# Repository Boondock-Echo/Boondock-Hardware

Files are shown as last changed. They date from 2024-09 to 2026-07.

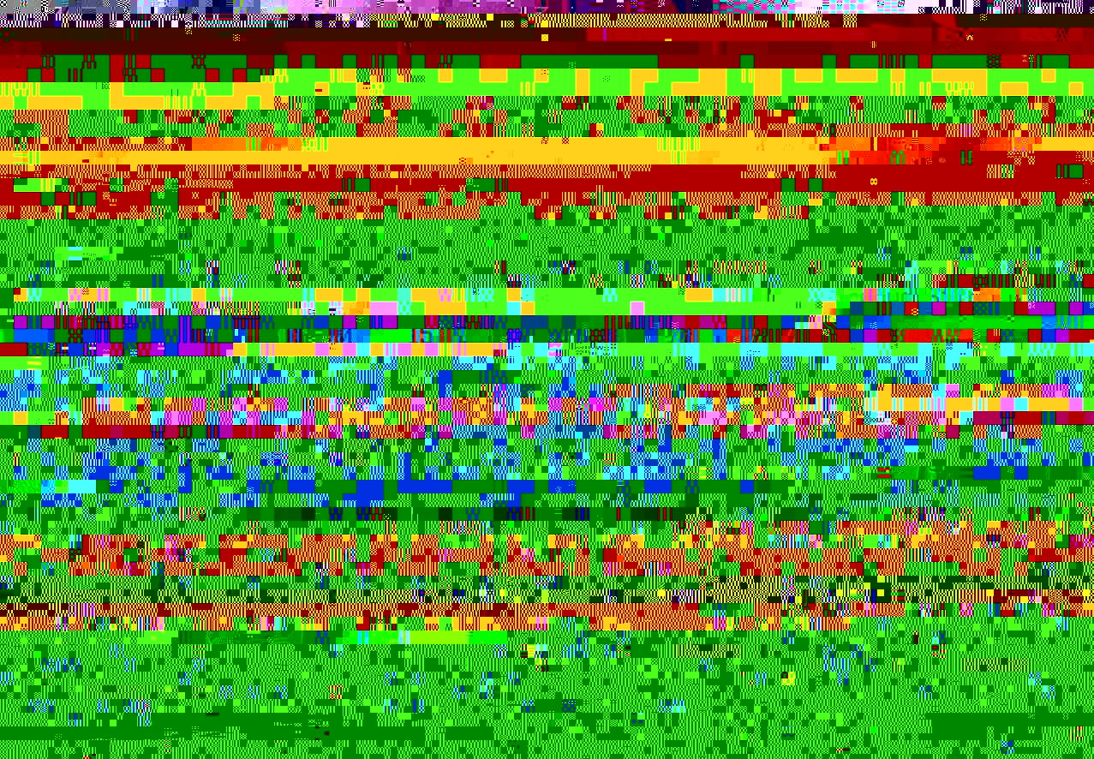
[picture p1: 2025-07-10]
Boondock-Hotel/Media-Assets/Images/BoondockHotel.jpg

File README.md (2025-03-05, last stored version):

# Boondock-Echo 
Hardware Design Files, BOM, Assembly Instructions, etc.

# 3D Files
Complete set of 3D .stl files for printing

# Case
This is the shipping box

# ESP32 Audiokit

# PCB
The KiCad design files for the board

# Software
The firmware for this project is in a different repository.  The easiest way to get started is to create an account at boondockecho.com and do a "firmware upgrade" process there.  Accounts are free.

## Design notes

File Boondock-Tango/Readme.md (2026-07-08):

## 3D Model: BoondockTango_CompleteAssembly v4

# Boondock Tango

**Boondock Tango** is here! We've decided to release a version you can buy and build at home—anywhere in the world. We firmly believe in the power of open-source goodness.

---

## About Boondock Tango

Boondock Tango is a **receive-only device for scanners and radios**

> **Note:** 
> - Currently works on Windows.
> - Mostly works on some flavors of Linux -- We're resolving some issues
> - macOS support is coming soon.

---

## Support Our Work

Designing innovative products takes time. 
If you’re inclined, please consider [buying us a cup of coffee or a can of Diet Dr. Pepper](https://www.paypal.com/ncp/payment/ZGAUS5ZF8CGH6).

---

## Parts & Components

You can find everything you need on eBay, AliExpress, or Amazon. Below is the list we used for the prototypes (we earn 2.5% from these Amazon links):

### Individual Parts
- [Micro USB Cord](https://amzn.to/41zijAU)
- [USB-C Female to USB A Female Adapter](https://amzn.to/3XxkQu3)
- [USB-C Male to USB A Male Cord](https://amzn.to/4iC329i)
- [Audio Kit](https://amzn.to/41BS4tv) 
 *Note: Currently, only this version of the Audio Kit is supported.*
- [MicroSD Card](https://amzn.to/3FczcK6)

---

## 3D Design Files

The 3D design files are available in our GitHub repository:

- [Boondock Tango 3D Design Files](https://github.com/Boondock-Echo/Boondock-Hardware/blob/main/Boondock-Tango/3D-Files/STL-Files/Boondock%20Tango%20RTC%202026_Boondock%20Tango%20RTC%202026_Body2.stl)
(https://github.com/Boondock-Echo/Boondock-Hardware/blob/main/Boondock-Tango/3D-Files/STL-Files/Boondock%20Tango%20RTC%202026_Boondock%20Tango%20RTC%202026_Body1.stl)

Feel free to fork, modify, and contribute!

---

## Special Offer

Once you build your Boondock Tango, please give us a chance to earn your business over at [Boondock Echo](http://www.boondockecho.com). Enjoy a **free month of premium service** to check it all out!

---

*Thank you for supporting open-source and DIY innovation!*

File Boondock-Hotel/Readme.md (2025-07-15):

## 3D Model: BoondockHotel_CompleteAssembly v4
3D Model Preview

# Boondock Hotel

**Boondock Hotel** is here! With all the uncertainty around tariffs, de minimis shipping delays, and duties, we've decided to release a version you can buy and build at home—anywhere in the world. We firmly believe in the power of open-source goodness.

---

## About Boondock Hotel

Boondock Hotel is a **receive-only device for scanners** currently designed to remotely control the [Uniden BC125AT](https://amzn.to/3DtEq3F) via our web interface. Control your device from anywhere with an internet connection!

> **Note:**  
> - Currently works on Windows.  
> - Mostly works on some flavors of Linux -- We're resolving some issues
> - macOS support is coming soon.

---

## Customization & Open Source Freedom

- **Modify and Build:**  
  Feel free to modify, manufacture, and even 3D print cases for profit anywhere in the world.
- **Sell Your Creations:**  
  Start an Etsy store, sell them on eBay, etc.  
  We don't take a percentage of your sales, but if something breaks, you'll need to support the customer.

---

## Support Our Work

Designing innovative products takes time. 
If you’re inclined, please consider [buying us a cup of coffee or a can of Diet Dr. Pepper](https://www.paypal.com/ncp/payment/ZGAUS5ZF8CGH6).

---

## Parts & Components

You can find everything you need on eBay, AliExpress, or Amazon. Below is the list we used for the prototypes (we earn 2.5% from these Amazon links):

### Amazon Wishlist
- [Amazon Wishlist](https://www.amazon.com/hz/wishlist/ls/38CLS1T7VIC0?ref_=wl_share)

### Individual Parts
- [Micro USB Cord](https://amzn.to/41zijAU)
- [USB Hub](https://amzn.to/3XATjrG)
- [Mini USB](https://amzn.to/4iCurYD)
- [USB-C Female to USB A Female Adapter](https://amzn.to/3XxkQu3)
- [USB-C Male to USB A Male Cord](https://amzn.to/4iC329i)
- [Audio Kit](https://amzn.to/41BS4tv)  
  *Note: Currently, only this version of the Audio Kit is supported.*
- [MicroSD Card](https://amzn.to/3FczcK6)
- [Uniden BC125AT Scanner](https://amzn.to/3DtEq3F)  
  *Note: Currently, only this version of the scanner is supported (more models may be added later).*
- [Ground Loop Isolator](https://amzn.to/4iAjIxV)

---

## 3D Design Files

The 3D design files are available in our GitHub repository:

- [Boondock Hotel 3D Design Files](3D-Files/Tall-Case)

Feel free to modify, fork, or contribute.

Here is how they all go together.

Assembly Video

---

## Special Offer

Once you build your Boondock Hotel, please give us a chance to earn your business over at [Boondock Echo](http://www.boondockecho.com). Enjoy a **free month of premium service** to check it all out!

---

*Thank you for supporting open-source and DIY innovation!*

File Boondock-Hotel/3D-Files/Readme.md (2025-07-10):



## 3D Model: BoondockHotel_CompleteAssembly v4

View STL file

[View the 3D model](https://raw.githubusercontent.com/Boondock-Echo/Boondock-Hardware/main/Boondock-Hotel/3DFiles/BoondockHotel_CompleteAssembly%20v4.stl)

These files are for the tall version of the Boondock Hotel!  Feel free to fork, print, sell, and update this design!

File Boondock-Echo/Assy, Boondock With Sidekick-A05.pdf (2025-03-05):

PART:

## Boondock With Sidekick

REV: A TITLE:

### Boondock With Sidekick

Confidential

The information contained in this document is the sole property of Cameca Instruments, Inc. Any reproduction, distribution, use, or disclosure is prohibited, whether in whole or in part, except as specifically authorized by Cameca Instruments, Inc.

## Sheet 1 of 1

CHANGE HISTORY
DATE | REV | DESCRIPTION OF CHANGE
12/28/2023 | A.01 | Initial Release
01/04/2024 | A.02 | Updates to assembly documentation
01/08/2024 | A.03 | Updates to assembly documentation, remove audio cable to separate document
05/02/2024 | A.04 | Updated to sidekick v3 (BOM), updated assembly instructions, updated 3D print files
03/03/2025 | A.05 | Changed back to full assembly

FILES ASSOCIATED WITH THIS DRAWING
FILE NAME | CONTENTS
PCBA, Sidekick v3 | Assembled PCB Zip File
Boondock With Sidekick BOM | Excel BOM
Boondock Echo Printed Files | STLs for printing

ASSEMBLY SECTION REVISION HISTORY LIST
Assembly | BOM | Assembly Instructions
A.01 | A.01 | A.01
A.02 | A.01 | A.02
A.03 | A.02 | A.03
A.04 | A.03 | A.04
A.05 | A.04 | A.05

Item | Description | QTY | Notes | Link1 | Link2 | Subs Allowed?
1 | PCBA, Sidekick v3 | 1 | Per customer gerber zip | NA | NA | No
2 | Audio Kit | 1 | Please use Jessinie store | https://www.amazon.com/JESSINIE-Bluetooth-ESP32-A1S-Development-Dual-core/dp/B0B5XKG5NK (https://www.amazon.com/JESSINIE-Bluetooth-ESP32-A1S-Development-Dual-core/dp/B0B5XKG5NK) | https://www.aliexpress.us/item/3256801407357108.html | No
3 | 3W 4 Ohm Speaker | 1 | | https://www.amazon.com/dp/B08JCHK7GR | https://www.aliexpress.us/item/3256804834669523.html? | Yes if mech fit
4 | Ribbon Cable, 14 position 1.27mm pitch | 72mm14 Position 1.27mm pitch for 2.54mm pitch IDC | | https://www.digikey.com/en/products/detail/3m/C3365-14-100/1107870 (https://www.digikey.com/en/products/detail/3m/C3365-14-100/1107870) | | Yes
5 | Ribbon Connector, IDC 2x7 2.54 pitch | 2 | IDC Header 2x7 (14pos), 2.54mm pitch | https://www.digikey.com/en/products/detail/on-shore-technology-inc/101-146/2794213 (https://www.digikey.com/en/products/detail/on-shore-technology-inc/101-146/2794213) | | Yes
Item | Description | QTY | Notes | Link1 | Link2 | Subs Allowed?
1 | Beveled_Top | 1 | BE_CASE_RC02_Beveled_Top-White Plastic Resin | NA | NA | No
2 | Beveled_Bottom | 1 | BE_CASE_RC02_Beveled_Bottom-White Plastic Resin | NA | NA | No
3 | ParametricButtons | 1 | BE_CASE_RC02_ParametricButtons-Black Plastic Resin | NA | NA | No
4 | SlideSwitch | 1 | BE_CASE_RC02_SlideSwitch-Black Plastic Resin | NA | NA | No
5 | Front Sticker | 1 | sfmd_Boondock labels_RC2-polyster label | NA | NA | No
7 | M2.5x6 Self Tap Screws | 6 | Speaker and PCB | | | Yes
8 | M3x12 Self Tap Screws | 4 | Lid | | | Yes
Boondock Echo With Sidekick BOM | A.04 | 3/3/2025

Electrical Assembly

Housing Items

## With Sidekick

### Assembly Instructions

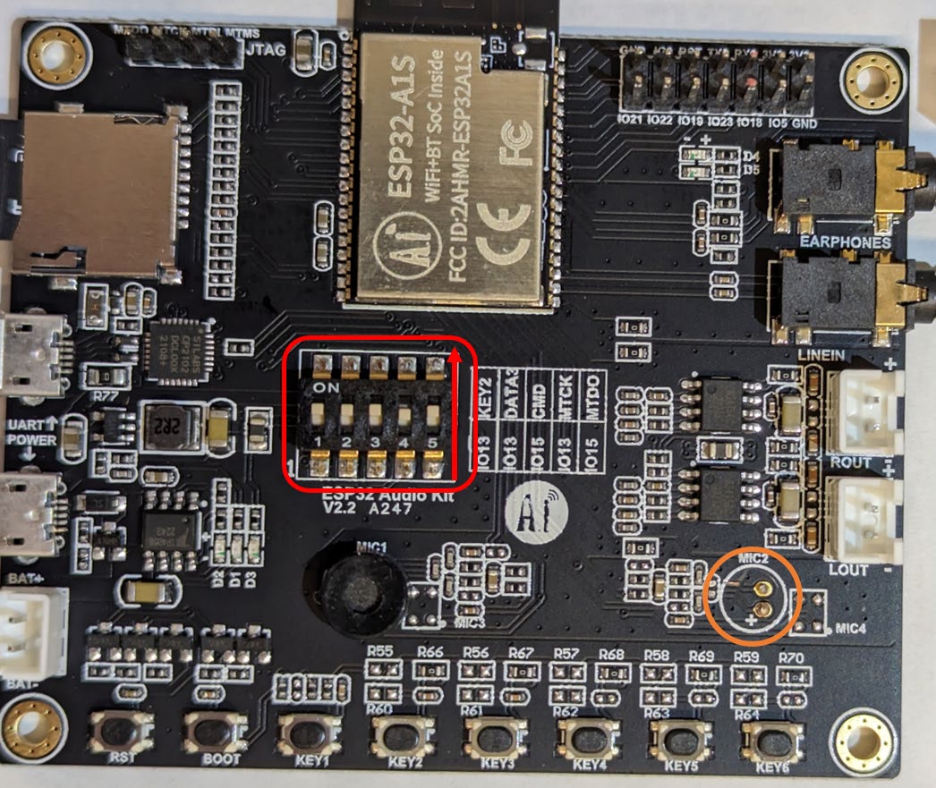
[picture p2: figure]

Confidential

The information contained in this document is the sole property of Cameca Instruments, Inc. Any reproduction, distribution, use, or disclosure is prohibited,

## Sheet 1 of 6

CHANGE HISTORY
DATE | REV | DESCRIPTION OF CHANGE
12/28/23 | A.01 | Initial Release
01/04/24 | A.02 | Updated notes per meeting on 12/29
01/08/24 | A.03 | Removed TRRS audio cable, split into own doc, a few other wording fixes from meeting on 1/5
05/02/24 | A.04 | Update to sidekick v3, changed poweron test instructions
03/03/25 | A.05 | Updated for full assembly (not just sidekick)

Assembly Instructions
1. Prepare Audiokit board
a. Remove secondary Mic (MIC2)
b. Set dip switches to the ON position
c. Load test firmware via the micro USB header labelled UART and the serial loader program provided.

## With Sidekick

### Assembly Instructions

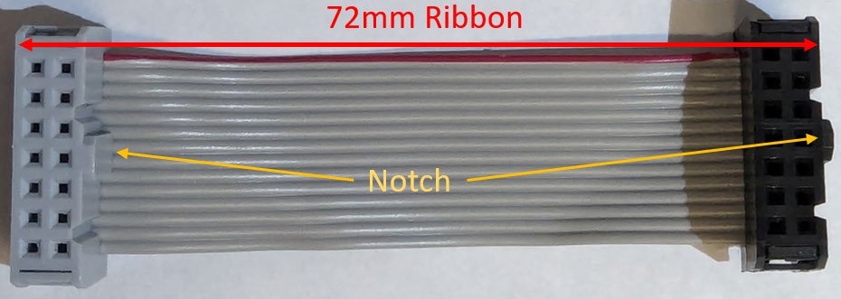
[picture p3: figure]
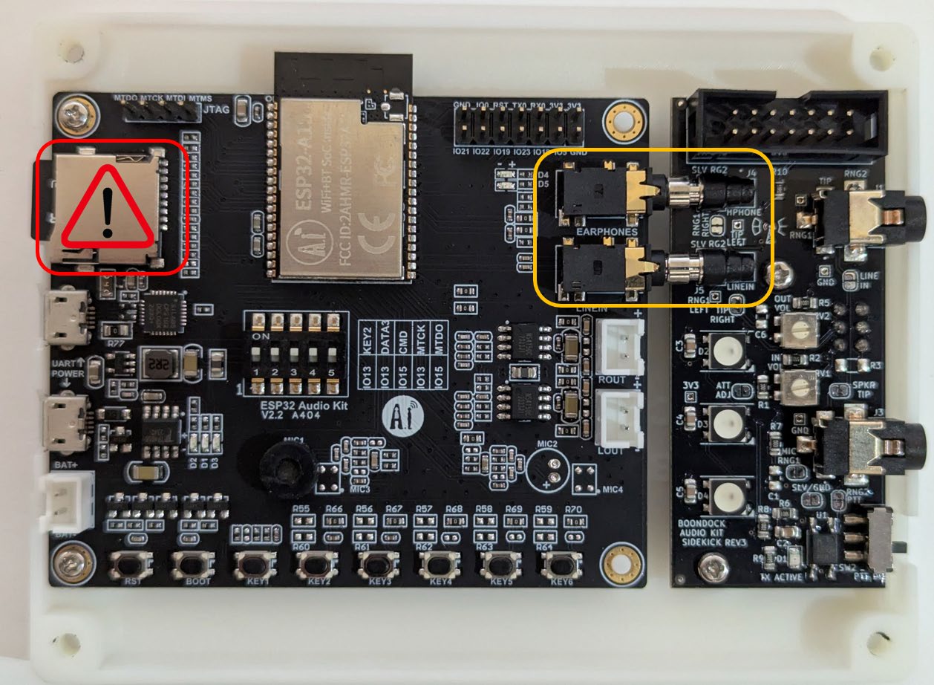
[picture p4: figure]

Confidential

The information contained in this document is the sole property of Cameca Instruments, Inc. Any reproduction, distribution, use, or disclosure is prohibited,

## Sheet 2 of 6

2. Create the Audiokit to Sidekick ribbon cable which is a standard 7x2 2.54mm spaced IDC cable.
a. Cut ribbon to 72mm length
b. Crimp 7x2 IDC headers on both ends, note the notch location on the picture below
3. Connect Sidekick to Audiokit
a. Carefully push in both audio connectors until they are seated, do not apply pressure to the micro SD card slot

## With Sidekick

### Assembly Instructions

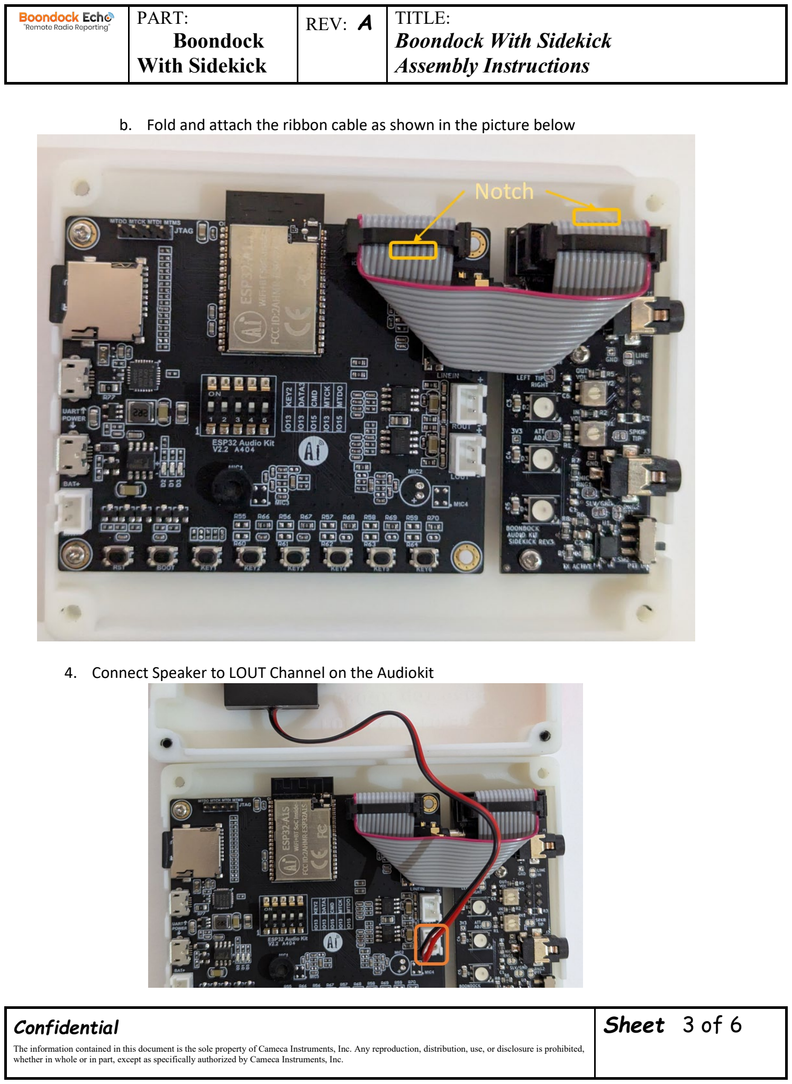
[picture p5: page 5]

Confidential

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

## Sheet 3 of 6

b. Fold and attach the ribbon cable as shown in the picture below
4. Connect Speaker to LOUT Channel on the Audiokit

## With Sidekick

### Assembly Instructions

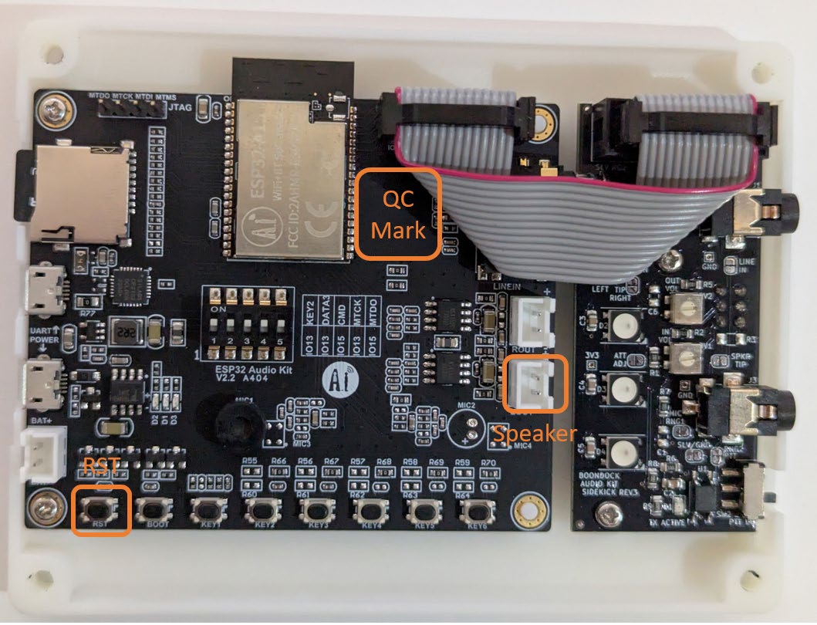
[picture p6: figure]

Confidential

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

## Sheet 4 of 6

5. Program and power on testing
a. Connect device via USB on UART
b. You will need to use the provided wireless router connected to ethernet for the device to connect to and update its firmware
c. Load the First.BIN firmware using the provided tool
d. Device will start flashing the LEDs red in sequence as it downloads the latest files
e. Once downloading has finished and self tests are complete the bottom light will remain green (and middle light may flicker) and the device will say “The Boondock Echo Team wants to thank you for choosing Boondock Echo”
f. Disconnect speaker so it can be mounted to the top shell
g. Place QC sticker/mark on the Audiokit board
6. Apply label to the top shell
a. Use the label fixture provided to fit into the button holes
b. Peel label and apply to top shell, folding over the edges
c. Smooth out any large bubbles

## With Sidekick

### Assembly Instructions

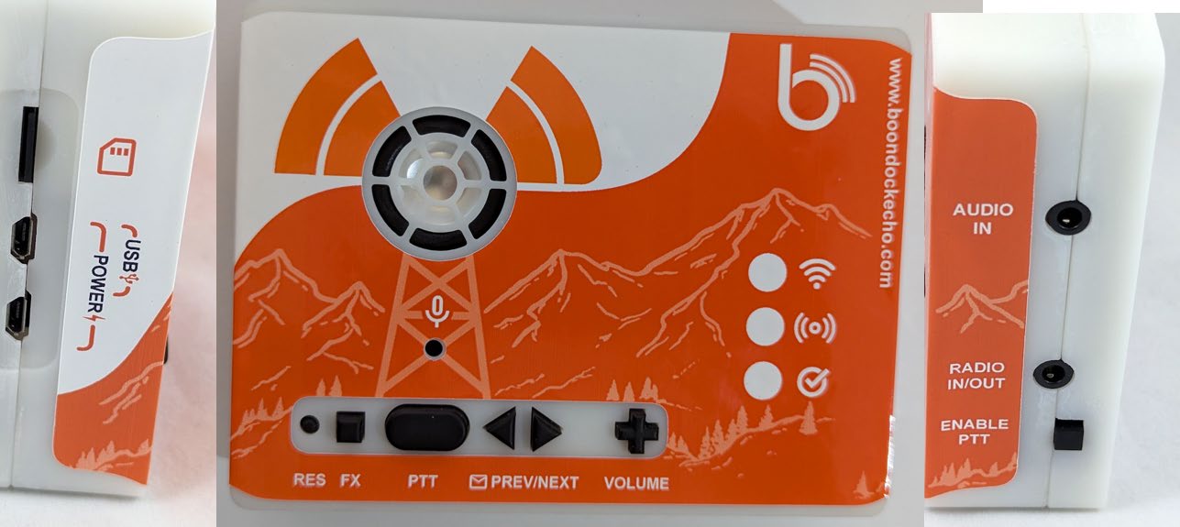
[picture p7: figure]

Confidential

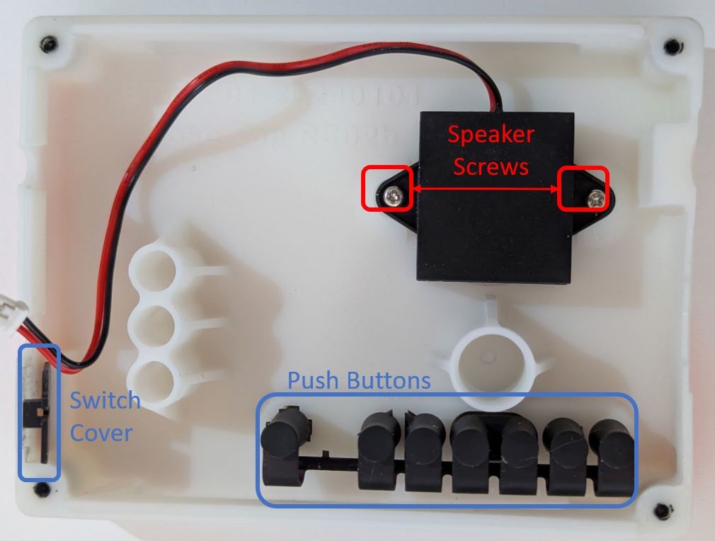
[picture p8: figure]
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

## Sheet 5 of 6

7. Assemble electronics into housing
a. Mount Speaker to Top shell with 2x M2.5x6mm self tap screws
b. Add switch cover with the opening switch opening facing towards the bottom shell
c. Add push buttons into the appropriate holes
d. Mount electrical subassembly to bottom shell using 4x M2.5x6mm self tap screws

## With Sidekick

### Assembly Instructions

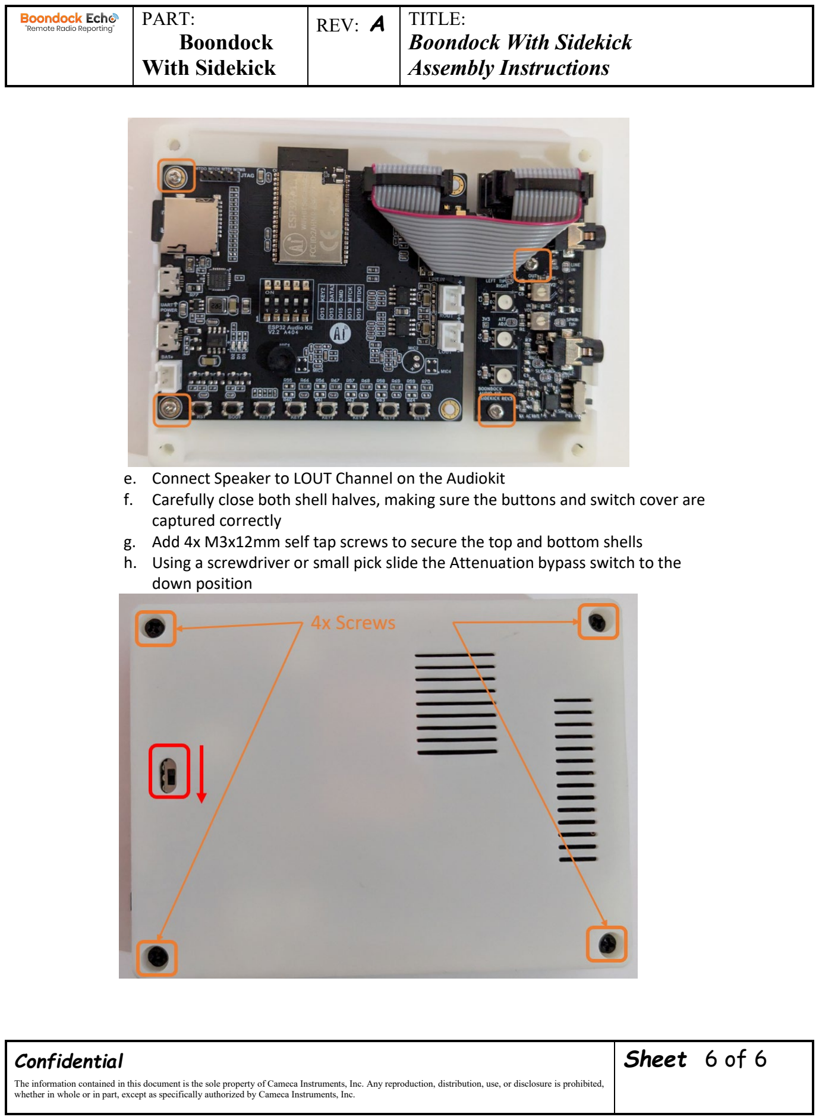
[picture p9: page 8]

Confidential

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

## Sheet 6 of 6

e. Connect Speaker to LOUT Channel on the Audiokit
f. Carefully close both shell halves, making sure the buttons and switch cover are captured correctly
g. Add 4x M3x12mm self tap screws to secure the top and bottom shells
h. Using a screwdriver or small pick slide the Attenuation bypass switch to the down position

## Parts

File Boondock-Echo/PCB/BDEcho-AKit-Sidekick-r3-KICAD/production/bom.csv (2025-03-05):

Designator | Footprint | Quantity | Value | LCSC Part #
C1, C6 | C_0805_2012Metric_Pad1.18x1.45mm_HandSolder | 2 | NP | NA
C2, C3, C4, C5 | C_0805_2012Metric_Pad1.18x1.45mm_HandSolder | 4 | 0.1u | C49678
D1 | LED_0805_2012Metric | 1 | GREEN | C73548
D2, D3, D4 | LED_WS2812B_PLCC4 | 3 | WS2812B | C2761795
FID1, FID2, FID3 | Fiducial_0.75mm_Mask1.5mm | 3 | Fiducial | NA
H1, H2 | MountingHole_2.7mm_M2.5_ISO7380_Pad | 2 | MTG | NA
J1, J3 | SJ2-3594A-SMT-TR | 2 | SJ2-3594A-SMT-TR
J2 | PinHeader_2x07_P2.54mm_Vertical | 1 | Conn_02x07_Odd_Even | C400039
J4, J5 | SP-3541_PCBWay | 2 | SP-3541 | MFABS
JP1, JP2, JP3, JP4, JP5, JP7, JP8 | SolderJumper-2_P1.3mm_Bridged2Bar_RoundedPad1.0x1.5mm | 7 | JMP | NA
JP6 | SolderJumper-2_P1.3mm_Open_RoundedPad1.0x1.5mm | 1 | Jumper_2_Open | NA
LOGO | LOGO | 1 | Fiducial
R1 | R_0805_2012Metric_Pad1.20x1.40mm_HandSolder | 1 | 3.3k | C26010
R10 | R_0805_2012Metric | 1 | 51 | C17738
R2 | R_0805_2012Metric_Pad1.20x1.40mm_HandSolder | 1 | 5.1k | C27834
R3 | R_1206_3216Metric_Pad1.30x1.75mm_HandSolder | 1 | NP | NA
R5, R6 | R_0805_2012Metric_Pad1.20x1.40mm_HandSolder | 2 | 1k | C17513
R7 | R_0805_2012Metric_Pad1.20x1.40mm_HandSolder | 1 | 100 | C17408
R8 | R_0805_2012Metric_Pad1.20x1.40mm_HandSolder | 1 | 10k | C17414
R9 | R_0805_2012Metric_Pad1.20x1.40mm_HandSolder | 1 | 680 | C17798
RV1, RV2 | TRIM_3314J-1-103E | 2 | 5k | C58391
SW1 | JS202011CQN | 1 | JS202011CQN | C221663
SW2 | SW_JS102011SAQN | 1 | SW_SLIDE_SPDT | C221660
TP1, TP2, TP3, TP4, TP6, TP9 | TestPoint_THTPad_1.0x1.0mm_Drill0.5mm | 6 | TP | NA
U1 | SO-4_4.4x3.6mm_P2.54mm | 1 | LTV-355T | C10803

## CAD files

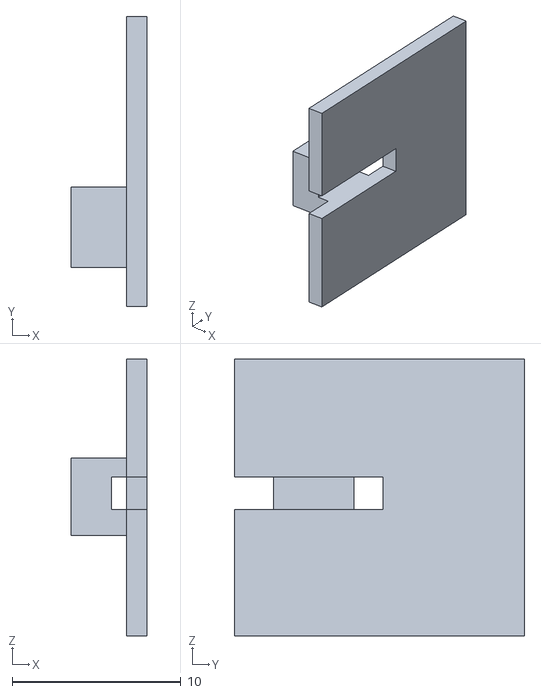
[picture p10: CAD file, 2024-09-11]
Boondock-Echo/Assy, Boondock With Sidekick-A05/3DFiles/BE_CASE_RC02_SlideSwitchOnly.stl
4.50 x 17.2 x 16.4

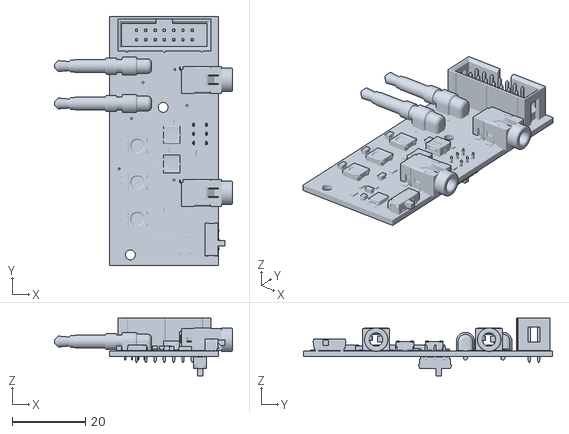
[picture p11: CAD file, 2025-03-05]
Boondock-Echo/PCB/BDEcho-AKit-Sidekick-r3-KICAD/BDEcho-AKit-Sidekick-r3.stl
48.7 x 68.1 x 15.8

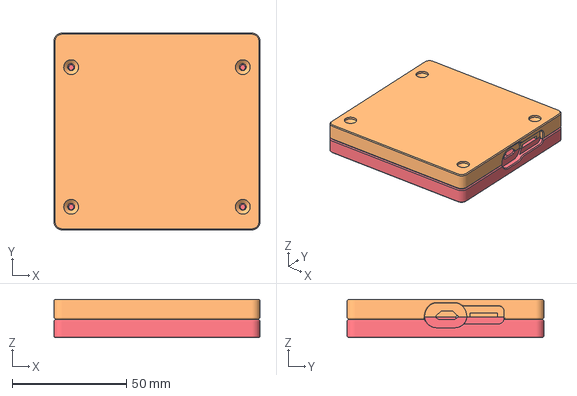
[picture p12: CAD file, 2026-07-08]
Boondock-Tango/3D-Files/3MF-Files/Boondock Tango RTC 2026.3mf
90.0 x 86.0 x 16.8 mm

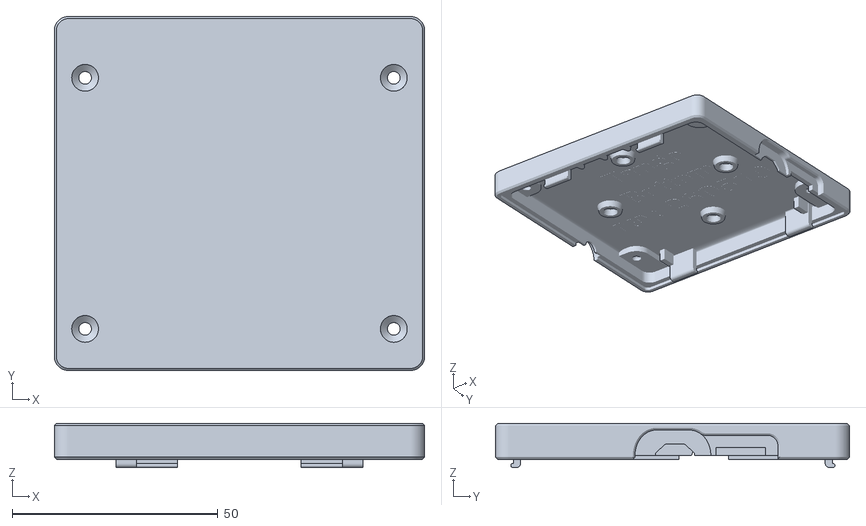
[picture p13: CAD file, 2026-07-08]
Boondock-Tango/3D-Files/STL-Files/Boondock Tango RTC 2026_Boondock Tango RTC 2026_Body3.stl
90.0 x 86.0 x 10.7

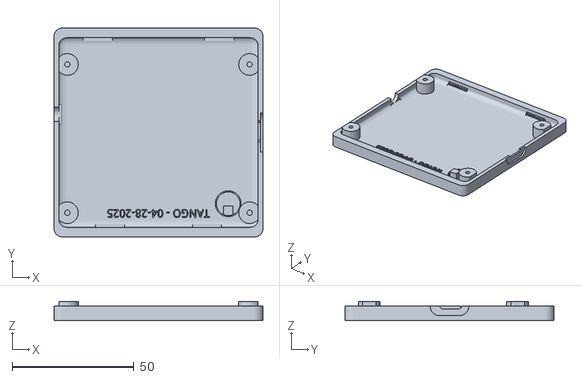
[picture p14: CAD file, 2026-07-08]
Boondock-Tango/Tango Scanner-BOTTOM.stl
86.0 x 86.0 x 7.90

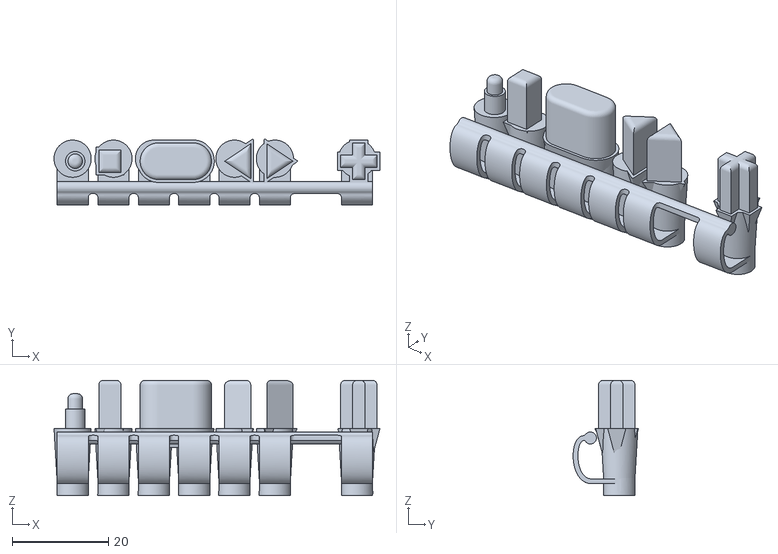
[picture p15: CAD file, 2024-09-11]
Boondock-Echo/Assy, Boondock With Sidekick-A05/3DFiles/BE_CASE_RC02_ParametricButtonsOnly.stl
67.8 x 13.7 x 24.0

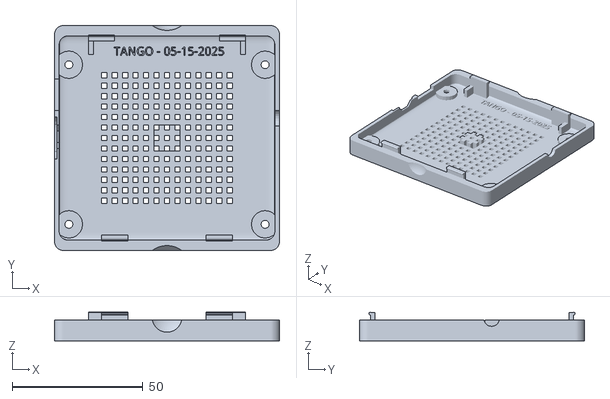
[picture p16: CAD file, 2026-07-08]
Boondock-Tango/Tango Scanner-TOP.stl
86.0 x 86.0 x 10.9

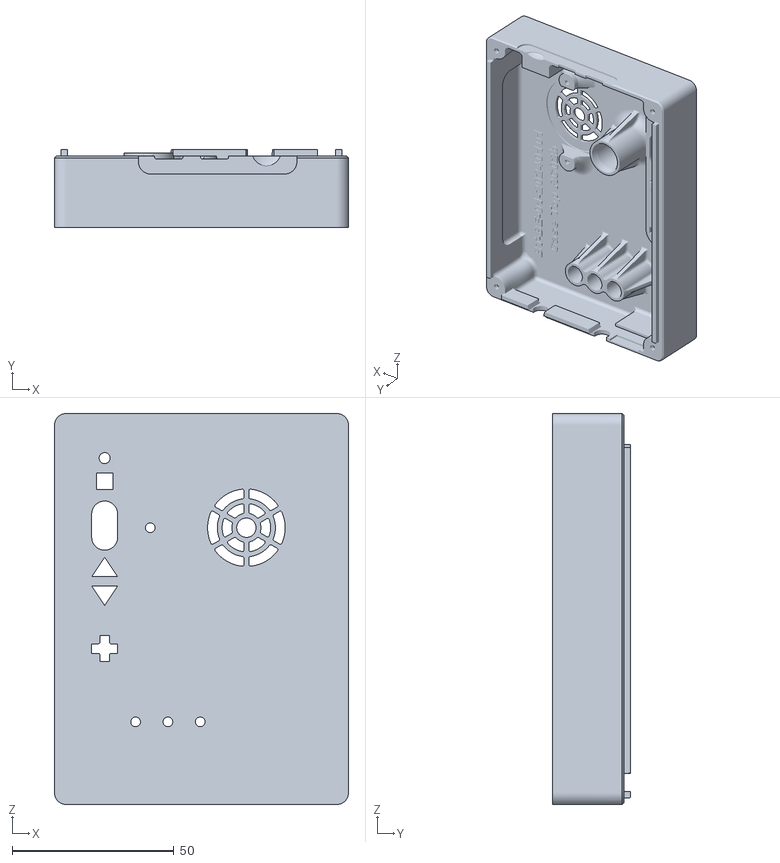
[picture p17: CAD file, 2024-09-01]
Boondock-Echo/Assy, Boondock With Sidekick-A05/3DFiles/BE_CASE_RC02_Beveled_Top.stl
91.0 x 24.0 x 121.0

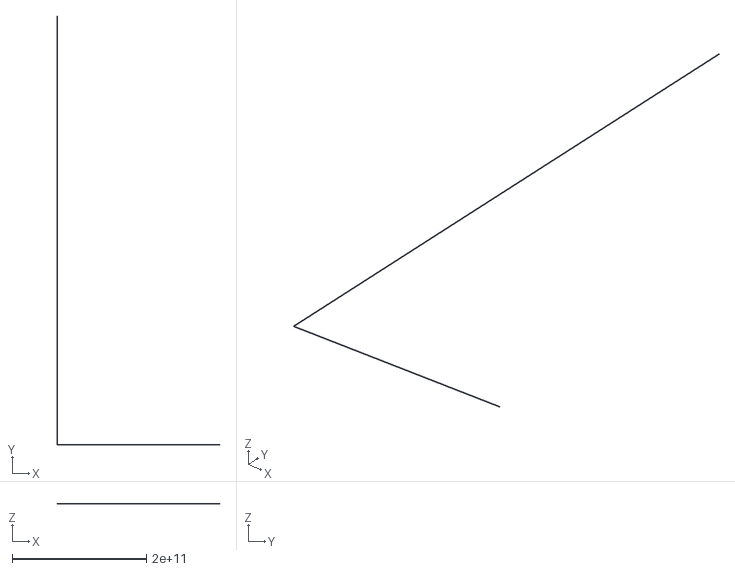
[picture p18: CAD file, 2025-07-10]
Boondock-Hotel/3D-Files/Tall-Case/STL-Files/USB-DovetailSlide.stl
246247981312.0 x 638897520382.0 x 4354848364.0

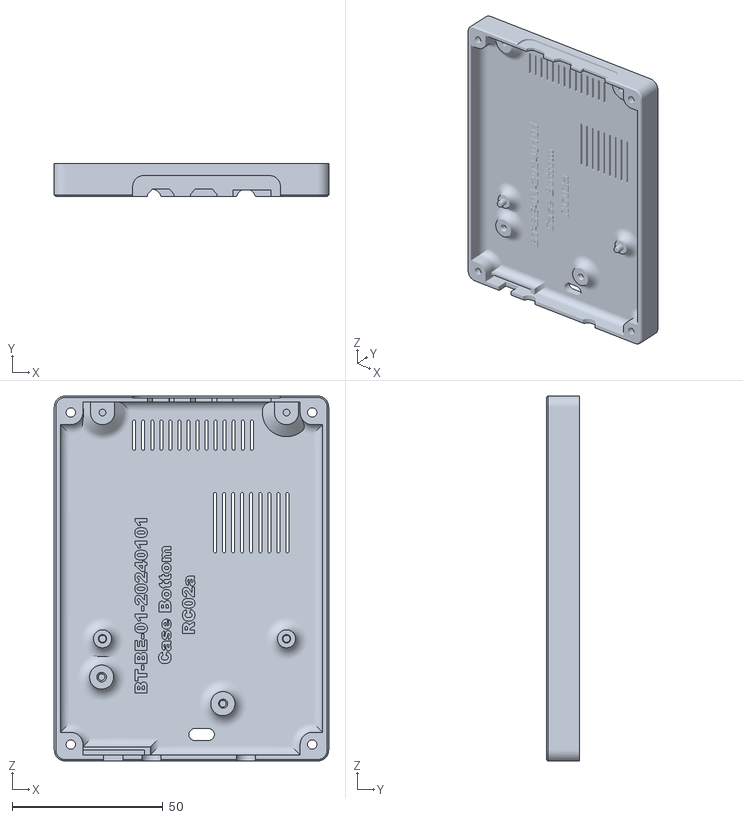
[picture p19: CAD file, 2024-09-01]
Boondock-Echo/Assy, Boondock With Sidekick-A05/3DFiles/BE_CASE_RC02_Beveled_Bottom.stl
91.0 x 11.0 x 121.0

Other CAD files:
Boondock-Hotel/3D-Files/Tall-Case/STL-Files/BoondockHotel-CompleteAssembly.stl
Boondock-Hotel/3D-Files/Tall-Case/3mf-Files/Tall-BoondockHotel-CompleteAssembly-RC1.3mf
Boondock-Hotel/3D-Files/Tall-Case/STL-Files/BoondockHotel-CompleteAssembly-v4.stl
Boondock-Hotel/3D-Files/Tall-Case/3mf-Files/AudiokitCarrierBoard-DovetailClamp-RC1.3mf
Boondock-Hotel/3D-Files/Tall-Case/STL-Files/AudiokitCarrierBoard-DovetailClamp-RC1-v2.stl
Boondock-Hotel/3D-Files/Tall-Case/3mf-Files/Tall-Case-RC1.3mf
Boondock-Tango/3D-Files/STL-Files/Boondock Tango RTC 2026_Boondock Tango RTC 2026_Body2.stl
Boondock-Hotel/3D-Files/Tall-Case/3mf-Files/Tall-ScannerGrabber-RC1.3mf
Boondock-Echo/Assy, Boondock With Sidekick-A05/3DFiles/BE_CASE_RC02_ParametricButtonsAndSwitch.stl
Boondock-Hotel/3D-Files/Tall-Case/3mf-Files/Tall-Baseplate-RC1.3mf
Boondock-Hotel/3D-Files/Tall-Case/3mf-Files/Tall-USBHolder-Sled-RC1.3mf
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

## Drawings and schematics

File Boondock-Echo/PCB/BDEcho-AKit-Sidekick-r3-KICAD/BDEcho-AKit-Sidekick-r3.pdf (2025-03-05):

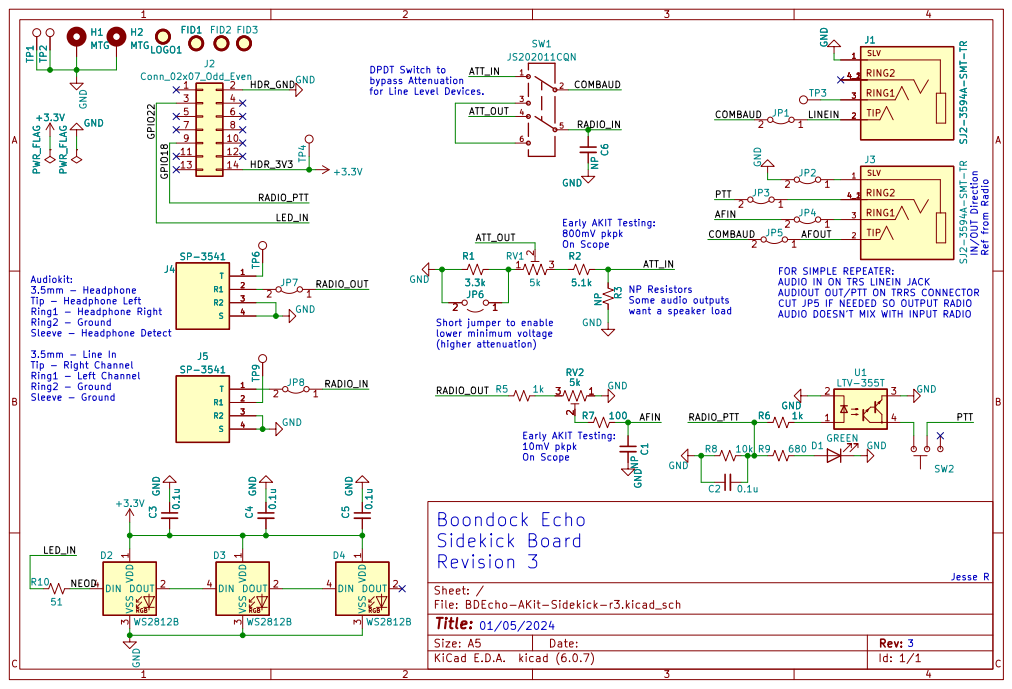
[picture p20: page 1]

FID2

DPDT Switch to bypass Attenuation

for Line Level Devices.

LINEIN
3 FOR SIMPLE REPEATER: AUDIO IN ON TRS LINEIN JACK

(higher attenuation) Audiokit: 3.5mm - Headphone

NP Resistors Some audio outputs

AUDIOUT OUT/PTT ON TRRS CONNECTOR
CUT JP5 IF NEEDED SO OUTPUT RADIO

Tip - Headphone Left
Ring1 - Headphone Right
Ring2 - Ground
Sleeve - Headphone Detect 3.5mm - Line In Tip - Right Channel

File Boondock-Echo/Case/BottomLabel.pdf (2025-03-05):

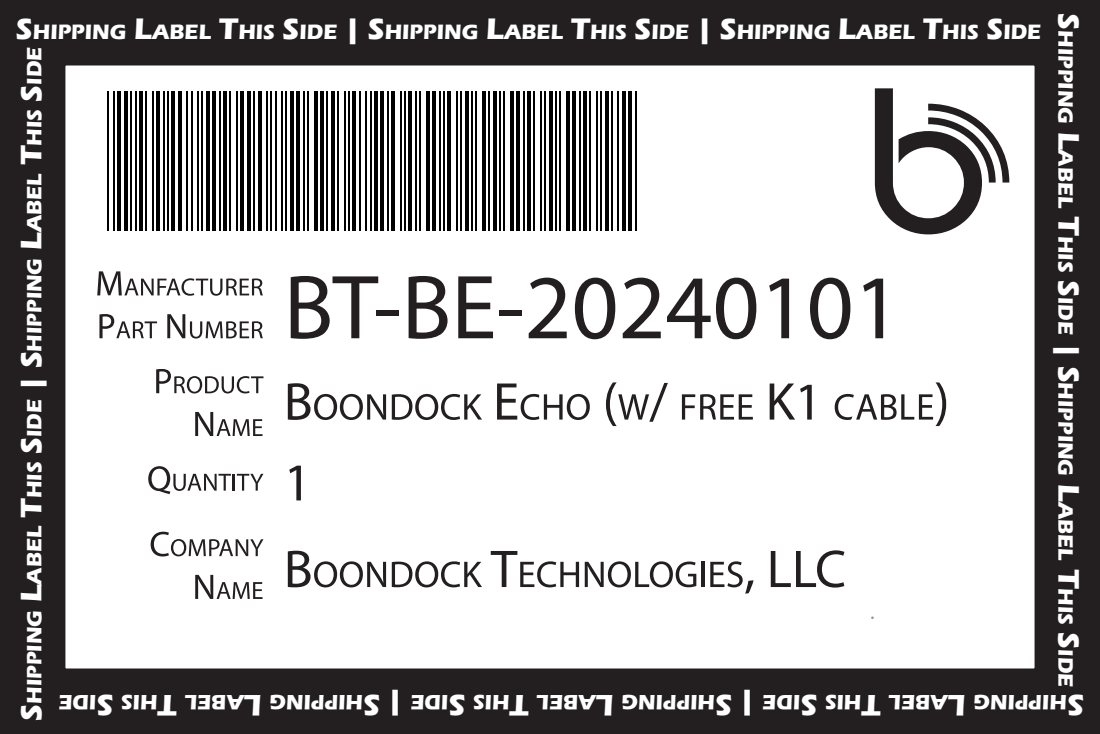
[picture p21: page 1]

SHIPPING LABEL THIS SIDE | SHIPPING LABEL THIS SIDE | SHIPPING LABEL THIS SIDE

SHIPPING LABEL THIS SIDE | SHIPPING LABEL THIS SIDE

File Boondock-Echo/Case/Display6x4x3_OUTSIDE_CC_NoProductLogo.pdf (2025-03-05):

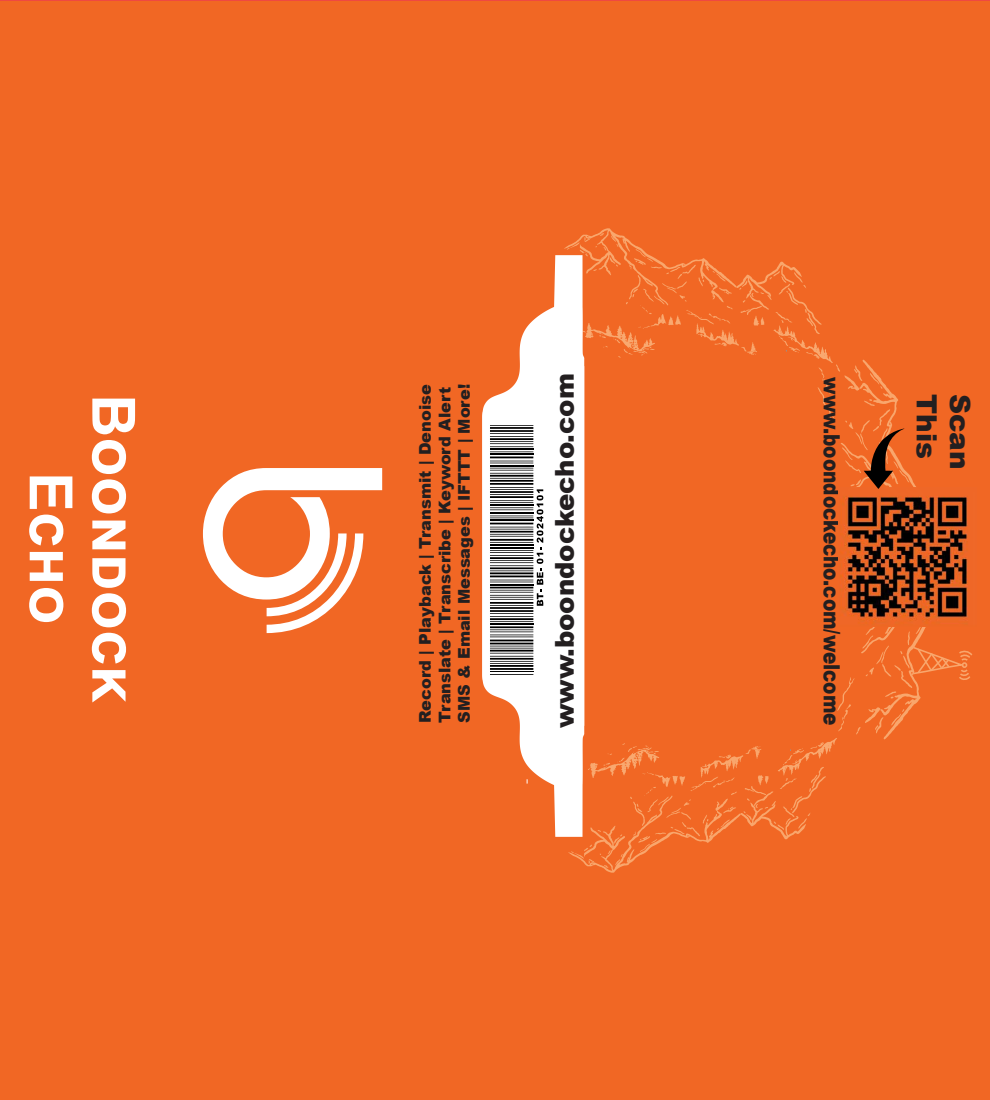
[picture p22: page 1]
BOONDOCK; ECHO; This; Scan

www.boondockecho.com

www.boondockecho.com/welcome

SMS & Email Messages | IFTTT | More!

Record | Playback | Transmit | Denoise

Translate | Transcribe | Keyword Alert

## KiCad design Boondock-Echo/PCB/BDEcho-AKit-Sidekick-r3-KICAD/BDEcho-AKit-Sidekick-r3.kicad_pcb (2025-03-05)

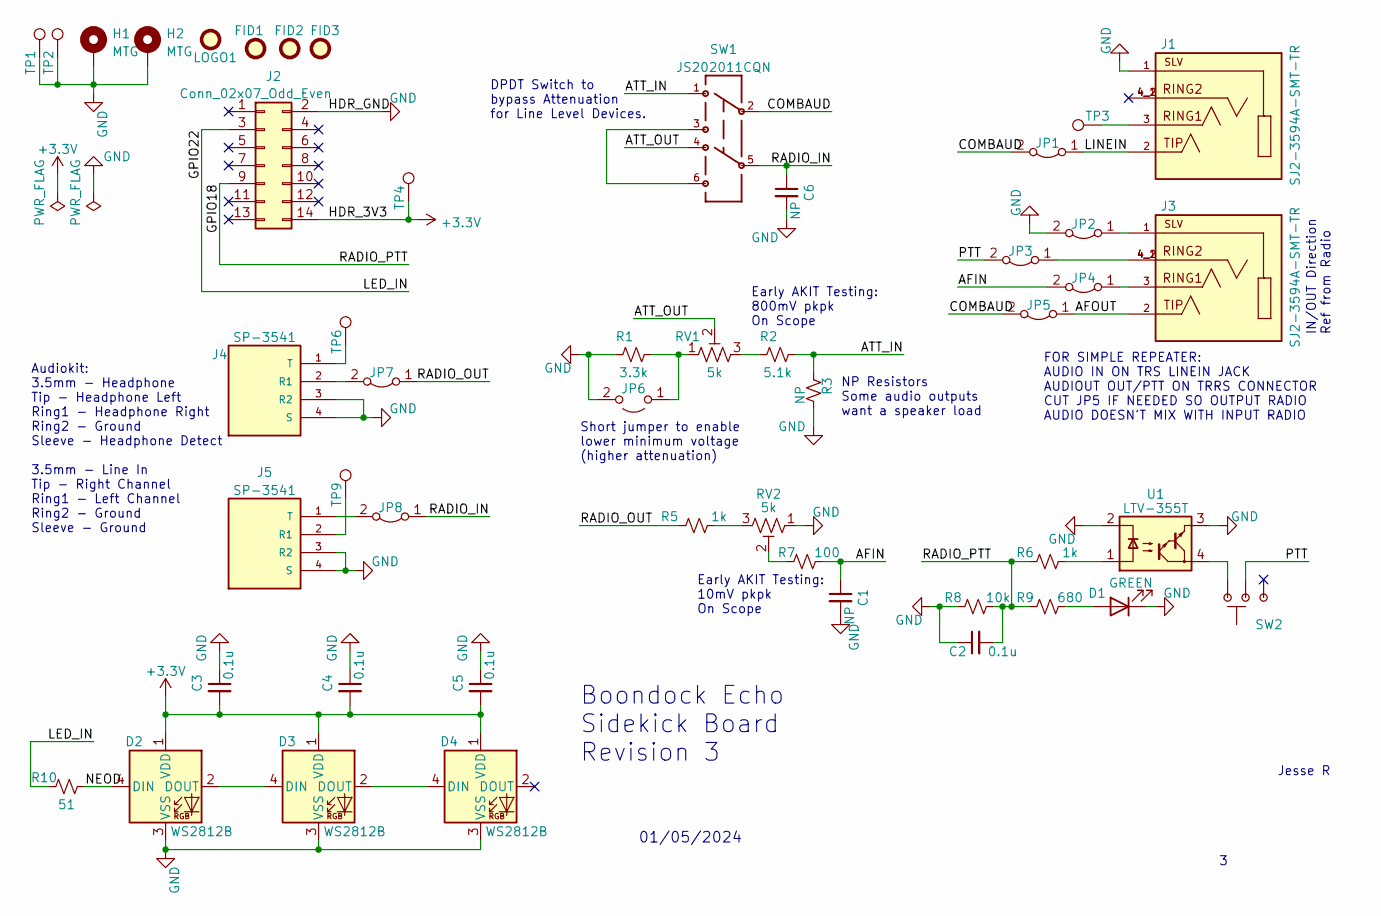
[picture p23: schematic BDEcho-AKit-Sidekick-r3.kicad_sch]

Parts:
C1, C6: NP; C_0805_2012Metric_Pad1.18x1.45mm_HandSolder; MFG # NA; JLCPCB NA
C2, C3, C4, C5: 0.1u; C_0805_2012Metric_Pad1.18x1.45mm_HandSolder; MFG # CC0805KRX7R9BB104; LCSC C49678
D1: GREEN; LED_0805_2012Metric; MFG # 17-21SYGC/S530-E2/TR8; LCSC C73548
D2, D3, D4: WS2812B; LED_WS2812B_PLCC4; MFG # WS2812B-B/T; JLCPCB C2761795
FID1, FID2, FID3: Fiducial; Fiducial_0.75mm_Mask1.5mm; MFG # NA; LCSC NA
H1, H2: MTG; MountingHole_2.7mm_M2.5_ISO7380_Pad; MFG # NA; LCSC NA
J1, J3: SJ2-3594A-SMT-TR; MFG PN SJ2-3594A-SMT-TR
J2: Conn_02x07_Odd_Even; PinHeader_2x07_P2.54mm_Vertical; MFG # A2547WV-N-2x7P; LCSC C400039
J4, J5: SP-3541; SP-3541_PCBWay; PART_REV 1.0; LCSC MFABS
JP1, JP2, JP3, JP4, JP5, JP7, JP8: JMP; SolderJumper-2_P1.3mm_Bridged2Bar_RoundedPad1.0x1.5mm; MFG # NA; LCSC NA
JP6: Jumper_2_Open; SolderJumper-2_P1.3mm_Open_RoundedPad1.0x1.5mm; MFG # NA; LCSC NA
LOGO1: Fiducial; LOGO; MFG # NA; LCSC NA
R1: 3.3k; R_0805_2012Metric_Pad1.20x1.40mm_HandSolder; MFG # 0805W8F3301T5E; LCSC C26010
R2: 5.1k; R_0805_2012Metric_Pad1.20x1.40mm_HandSolder; MFG # 0805W8F5101T5E; LCSC C27834
R3: NP; R_1206_3216Metric_Pad1.30x1.75mm_HandSolder; MFG # NA; LCSC NA
R5, R6: 1k; R_0805_2012Metric_Pad1.20x1.40mm_HandSolder; MFG # 0805W8F1001T5E; LCSC C17513
R7: 100; R_0805_2012Metric_Pad1.20x1.40mm_HandSolder; MFG # 0805W8F1000T5E; LCSC C17408
R8: 10k; R_0805_2012Metric_Pad1.20x1.40mm_HandSolder; MFG # 0805W8F1002T5E; LCSC C17414
R9: 680; R_0805_2012Metric_Pad1.20x1.40mm_HandSolder; MFG # 0805W8F6800T5E; JLCPCB C17798
R10: 51; R_0805_2012Metric; MFG # 0805W8F510JT5E; LCSC C17738
RV1, RV2: 5k; TRIM_3314J-1-103E; MFG # 3314J-1-502E; LCSC C58391
SW1: JS202011CQN; MFG PN JS202011CQN; LCSC C221663
SW2: SW_SLIDE_SPDT; SW_JS102011SAQN; MFG # JS102011SAQN; LCSC C221660
TP1, TP2, TP3, TP4, TP6, TP9: TP; TestPoint_THTPad_1.0x1.0mm_Drill0.5mm; MFG # NA; JLCPCB NA
U1: LTV-355T; SO-4_4.4x3.6mm_P2.54mm; MFG # LTV-355T; JLCPCB C10803

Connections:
+3.3V: C3.2, C4.2, C5.2, D2.1 (VDD), D3.1 (VDD), D4.1 (VDD), J2.14, TP4.1
/AFIN: C1.1, JP4.2 (B), R7.1
/AFOUT: J3.2, JP5.1 (A)
/ATT_IN: R2.1, R3.2, SW1.1
/ATT_OUT: RV1.2, SW1.4
/COMBAUD: JP1.2 (B), JP5.2 (B), SW1.2
/GPIO18: C2.2, J2.9, R6.2, R8.1, R9.2
/GPIO22: J2.3, R10.2
/LINEIN: J1.2, JP1.1 (A)
/NEOD: D2.4 (DIN), R10.1
/PTT: JP3.2 (B), SW2.2 (CO)
/RADIO_IN: C6.1, JP8.1 (A), SW1.5
/RADIO_OUT: JP7.1 (A), R5.2
GND: C1.2, C2.1, C3.1, C4.1, C5.1, C6.2, D1.1 (K), D2.3 (VSS), D3.3 (VSS), D4.3 (VSS), H1.1, H2.1, J1.1, J2.2, J4.3 (R2), J4.4 (S), J5.3 (R2), J5.4 (S), JP2.2 (B), JP6.2 (B), R1.2, R3.1, R8.2, RV2.1, TP1.1, TP2.1, U1.2, U1.3
unnamed: D1.2 (A), R9.1
unnamed: D2.2 (DOUT), D3.4 (DIN)
unnamed: D3.2 (DOUT), D4.4 (DIN)
unnamed: J1.3, TP3.1
unnamed: J3.1, JP2.1 (A)
unnamed: J3.3, JP4.1 (A)
unnamed: J3.4_1, J3.4_2, JP3.1 (A)
unnamed: J4.1 (T), TP6.1
unnamed: J4.2 (R1), JP7.2 (B)
unnamed: J5.1 (T), JP8.2 (B)
unnamed: J5.2 (R1), TP9.1
unnamed: JP6.1 (A), R1.1, RV1.1
unnamed: R2.2, RV1.3
unnamed: R5.1, RV2.3
unnamed: R6.1, U1.1
unnamed: R7.2, RV2.2
unnamed: SW1.3, SW1.6
unnamed: SW2.1 (NC), U1.4

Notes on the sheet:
NP Resistors Some audio outputs want a speaker load
Early AKIT Testing: 800mV pkpk On Scope
Audiokit: 3.5mm - Headphone Tip - Headphone Left Ring1 - Headphone Right Ring2 - Ground Sleeve - Headphone Detect 3.5mm - Line In Tip - Right Channel Ring1 - Left Channel Ring2 - Ground Sleeve - Ground
Early AKIT Testing: 10mV pkpk On Scope
Short jumper to enable lower minimum voltage (higher attenuation)
Boondock Echo Sidekick Board Revision 3
Jesse R
01/05/2024
FOR SIMPLE REPEATER: AUDIO IN ON TRS LINEIN JACK AUDIOUT OUT/PTT ON TRRS CONNECTOR CUT JP5 IF NEEDED SO OUTPUT RADIO AUDIO DOESN'T MIX WITH INPUT RADIO
IN/OUT Direction Ref from Radio
DPDT Switch to bypass Attenuation for Line Level Devices.

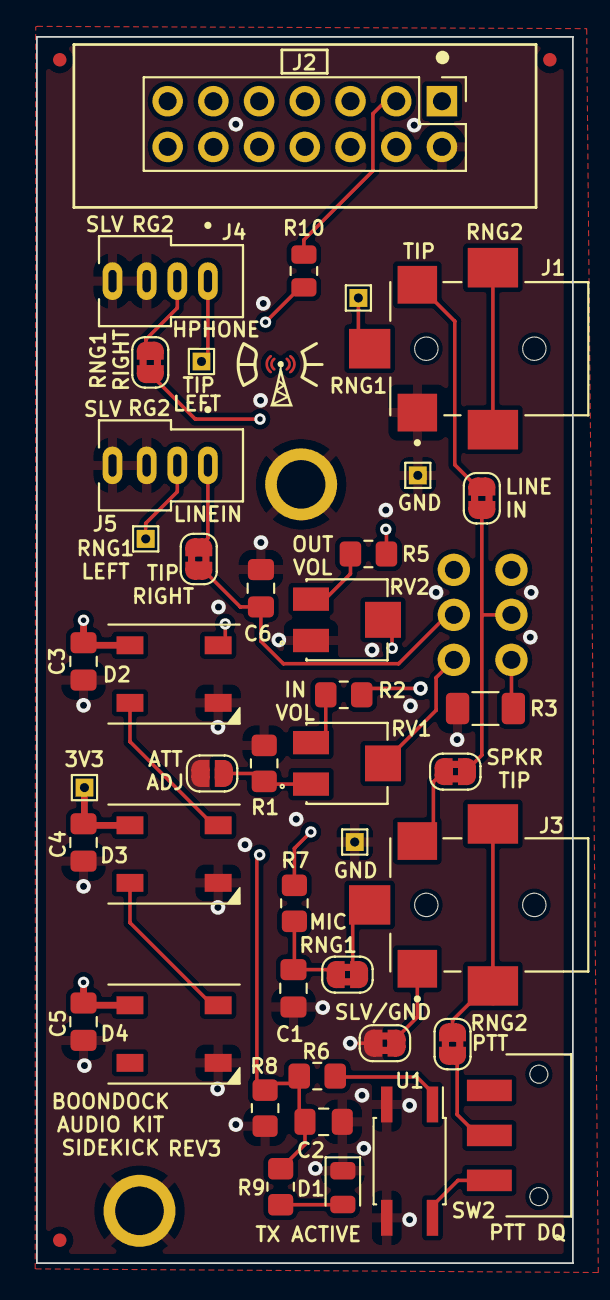
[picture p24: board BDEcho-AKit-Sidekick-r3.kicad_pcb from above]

Board: 4 copper layers, 29.8 x 68.1 mm, 49 parts (1 on the bottom side), 32 nets.

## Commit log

2023-10-02 First commit of hardware files
    First commit of hardware files, contains kicad CCA files, manufacturing files, 3D files, schematic for purchased audio kit board, some assembly notes, assembly bom
    [BDEcho-AKit-Sidekick-r2.kicad_pcb, BDEcho-AKit-Sidekick-r2.kicad_sch, BDEcho_Back.stl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]
2023-10-10 Add files via upload
    Updated back for a little more room around board
    [BDEcho_Back.stl]
2023-10-17 Add files via upload
    Updated back, front, and buttons
    [BDEcho_Back.stl, BDEcho_CaptiveButtons.stl, BDEcho_FrontFace.stl]
2023-10-27 Add files via upload
    Updated STLs and tinkercad link
    [BDEcho_Back.stl, BDEcho_CaptiveButtons.stl, BDEcho_LightPipeCover.stl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]
2023-10-27 Delete 3D Files directory
    Need to refresh Files
    [BDEcho_Back.stl, BDEcho_CaptiveButtons.stl, BDEcho_FrontFace.stl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]
2023-10-27 Add files via upload
    Added 3D Files and up to date TinkerCAD link
    [Boondock-Bottom.stl, Boondock-Buttons.stl, Boondock-Light-pipe-Cover.stl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]
2024-09-01 Delete 3D Files directory
    Removing very old files and updating
    [Boondock-Bottom.stl, Boondock-Buttons.stl, Boondock-Light-pipe-Cover.stl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]
2024-09-01 Add files via upload
    RC02 files
    [BE_CASE_BOTTOM_RC2B.stl, BE_CASE_PARAMETRICBUTTONS.stl, BE_CASE_TOP_RC2B.stl]
2024-09-11 Add separate files for buttons and slide switch
    [ParametricButtons_ButtonsOnly.stl, ParametricButtons_SlideSwitch.stl]
2025-03-05 Delete ElectricalAssembly-BOM.csv
    Removing all old design files and uploading a fresh batch
    [ElectricalAssembly-BOM.csv]
2025-03-05 Delete Assembly Notes directory
    Removing all old files for refresh
2025-03-05 Delete ESP32-Audiokit directory
    Removing all of the old design files for a refresh
2025-03-05 Delete Hardware directory
    Removing all the old design files for a refresh
    [BE_CASE_BOTTOM_RC02b v3.f3d, BE_CASE_BOTTOM_RC2B.stl, BE_CASE_PARAMETRICBUTTONS.stl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]
2025-03-05 Add files via upload
    3D print files for the Boondock Echo RC03
    [BE_CASE_RC02_Beveled_Bottom.stl, BE_CASE_RC02_Beveled_Top.stl, BE_CASE_RC02_ParametricButtonsAndSwitch.stl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]
2025-03-05 Add files via upload
    Assembly Instrucitons and Files
    [BDEcho-AKit-Sidekick-r3-BOM-030424.csv, BE_CASE_RC02_Beveled_Bottom.stl, BE_CASE_RC02_Beveled_Top.stl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]
2025-03-05 Delete Case directory
    Wrong location
2025-03-05 Add files via upload
    Adding All the PCB Files
    [BDEcho-AKit-Sidekick-r3-BOM-030424.csv, BDEcho-AKit-Sidekick-r3.kicad_pcb, BDEcho-AKit-Sidekick-r3.kicad_sch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]
2025-03-10 Add files via upload
    Initial Commit
    [AudiokitCarrierBoard_DovetailClamp_RC1 v2.3mf, AudiokitCarrierBoard_DovetailClamp_RC1 v2.f3d, Baseplate_Tall_RC1 v2.3mf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]
2025-03-10 Organized files and added information to the readme.md
    Organized files and added information to the readme.md
    [AudiokitCarrierBoard_DovetailClamp_RC1.3mf, AudiokitCarrierBoard_With_DovetailClamp_RC1.f3d, BoondockTango_CompleteAssembly.stl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]
2025-03-10 Added .stl and image
    [AudiokitCarrierBoard_DovetailClamp_RC1 v2.stl, BoondockTango_CompleteAssembly v4.stl, TallBC125ATScannerGrabber.stl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]
2025-03-11 Add Assembly Gif
2025-03-11 Update Readme.md
    Added an assembly .gif
2025-03-14 Rename USB_DovetailSlide (1).stl to USB_DovetailSlide.stl
    [USB_DovetailSlide.stl]
2025-07-10 Fixing the multiple products with duplicate names issue
    We have several products sharing the "Tango" name -- moving the large scanner carrier to Boondock Hotel, the small box to Boondock Tango, and the scanner controller to Boondock Wilco. While the large carrier had the name first, it's the least utilized product and will cause the least confusion amongst the user base.
    [AudiokitCarrierBoard-DovetailClamp-RC1-v2.stl, AudiokitCarrierBoard-DovetailClamp-RC1.3mf, AudiokitCarrierBoard-With-DovetailClamp-RC1.f3d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]
2025-07-15 Adding Assembly Gif back in.
    Adding Assembly Gif back in.
2026-02-16 Tango STL files
    [Tango Scanner-BOTTOM.stl, Tango Scanner-TOP.stl]
2026-07-08 Updating Tango Design files for plastic snap case with screw support.
    Updating Tango Design files for plastic snap case with screw support.
    [Boondock Tango RTC 2026.3mf, Boondock Tango RTC 2026.f3d, Boondock Tango RTC 2026_Boondock Tango RTC 2026_Body2.stl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]
2026-10-28 Updating 3d Print files to latest versions
    Minor changes to tango case to include beveled mating edges, increased grip in tabs, and other minor changes.
2026-10-28 Adding latest .stl files for box, .avif and .png files for cables
2026-10-29 Adding Tall Tango Box Option for Batteries.
    Tall Tango Box designed to allow a small LiFePO4 battery pack to be added to the device.
